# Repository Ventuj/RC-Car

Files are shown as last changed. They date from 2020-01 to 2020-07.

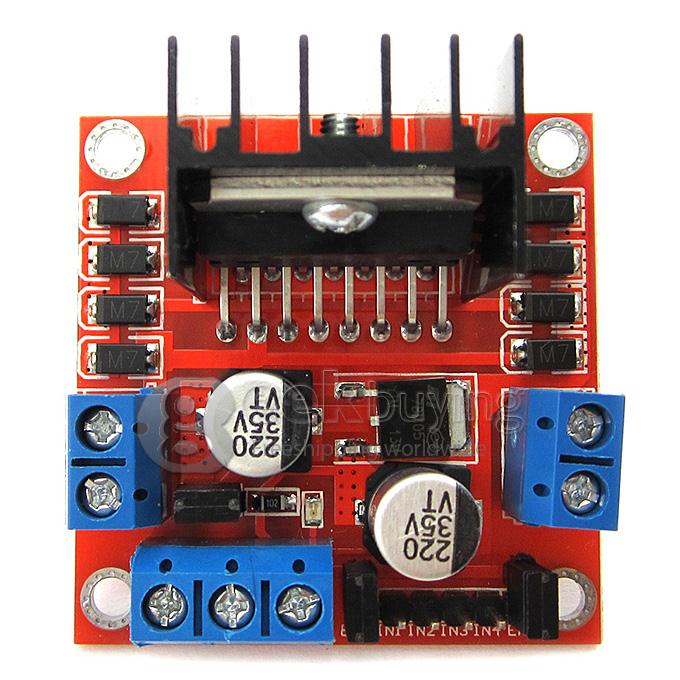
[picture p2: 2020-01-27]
Docs/Img/L298N View.jpg

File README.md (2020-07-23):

# Remote 4x4 Car
Three different version 4x4 RC car with arduino.

# Last Update
Last PCB Shield design is [Gerber_Arduino Mega Shield V2_20200217124525.zip](https://github.com/Daniele-Venturin/RC-Car/blob/master/Docs/Altro/Gerber_Arduino%20Mega%20Shield%20V2_20200217124525.zip)
## V1.0 (IR) Relè & L298N
###### Components
- 1x RGB Led (Optional)
- 2x 1kohm resistors
- 2x 2 Relay
- 4x DC Motors
- 1x HC-SR04 (Ultrasonic Sensor)
- 1x 1838B (iR Receiver)
- 1x Arduino Nano or Arduino UNO
- 1x Buzzer (Optional)
- 2x Battery pack 7-12V

###### PinOut
LED Status
- D3 ➞ Red
- D4 ➞ Green

Signal Reciver
- D5 ➞ IR reciver

Ultrasonic Sensor
- D6 ➞ Echo 
- D7 ➞ Trig

Relay
- D8 ➞ SX1
- D9 ➞ SX2
- D10 ➞ DX1
- D11 ➞ DX2

Sound
- D12 ➞ Buzzer

## V2.0 (Bluetooth)
###### Components
- 1x Custom PCB Shield
- 1x L298N DC Motor driver
- 1x Buzzer (optional)
- 1x RGB Led (optional)
- 1x HC-05 (Bluetooth Module)
- 4x HC-SR04 (Ultrasonic Sensor)
- 4x DC Motors
- 1x Arduino MEGA 2560
- 1x Battery Pack (11,1V 2200 mAh)
- 1x BMS 3S 20C

###### PinOut
Digitali
LED Status
- D8 ➞ Green
- D9 ➞ Red

Sound
- D10 ➞ Buzzer
- D11 ➞ Fari Posteriori
- D12 ➞ Faro Anteriori

Sensori
- D22 ➞ Trig 1
- D23 ➞ Echo 1
- D24 ➞ Trig 2
- D25 ➞ Echo 2
- D26 ➞ Trig 3
- D27 ➞ Echo 3
- D28 ➞ Trig 4
- D29 ➞ Echo 4

Driver Motori
- D2 ➞ Enable 1
- D3 ➞ Input 1
- D4 ➞ Input 2
- D5 ➞ Input 3
- D6 ➞ Input 4
- D7 ➞ Enable 2

Analogici
- A0 ➞ Stop Button 
- A1 ➞ Fotoresistenza

## V3.0 (WI-FI)
###### Components
- 1x Custom Motherboard PCB
- 4x 1kohm resistors (R1-R2-R3-R4)
- 2x 33kohm resistors (R5-R6)
- 1x L298N DC Motor driver
- 1x Buzzer (Optional)
- 1x RGB Led (Optional)
- 1x ESP8266 (WI-FI Module)
- 4x HC-SR04 (Ultrasonic Sensor)
- 4x DC Motors
- 1x Arduino MEGA
- 1x Battery Pack (11,1V 2200 mAh)
- 1x BMS 3S 20C

###### PinOut
Digitali
LED Status
- D8 ➞ Green
- D9 ➞ Red

Sound
- D10 ➞ Buzzer
- D11 ➞ Fari Posteriori
- D12 ➞ Faro Anteriori

Sensori
- D22 ➞ Trig 1
- D23 ➞ Echo 1
- D24 ➞ Trig 2
- D25 ➞ Echo 2
- D26 ➞ Trig 3
- D27 ➞ Echo 3
- D28 ➞ Trig 4
- D29 ➞ Echo 4

Driver Motori
- D2 ➞ Enable 1
- D3 ➞ Input 1
- D4 ➞ Input 2
- D5 ➞ Input 3
- D6 ➞ Input 4
- D7 ➞ Enable 2

Analogici
- A0 ➞ Stop Button 
- A1 ➞ Fotoresistenza

## Docs

###### Wire diagram 

###### Gerber file PCB
Top view of PCB

Top 

Bottom view of PCB

Bottom

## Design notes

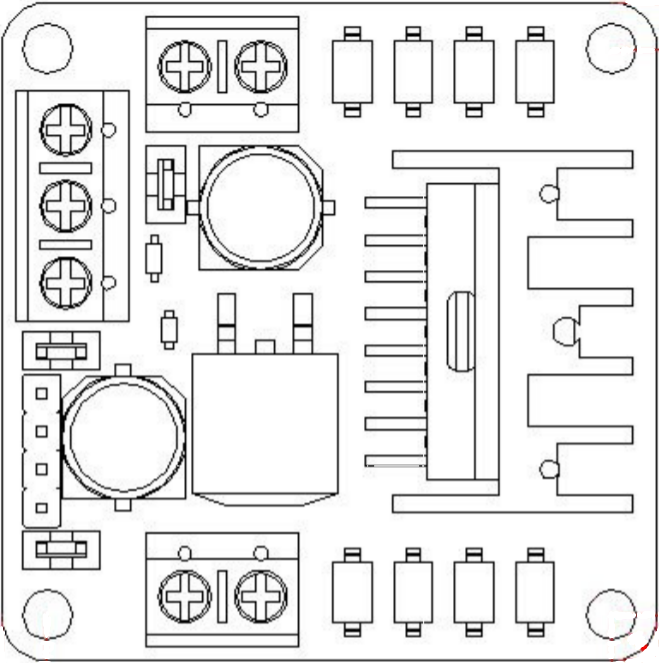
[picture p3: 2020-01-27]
Docs/Img/L298N.png

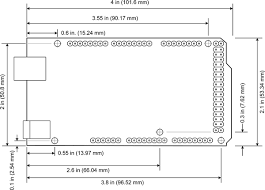
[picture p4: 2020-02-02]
Docs/Img/dimmension.png

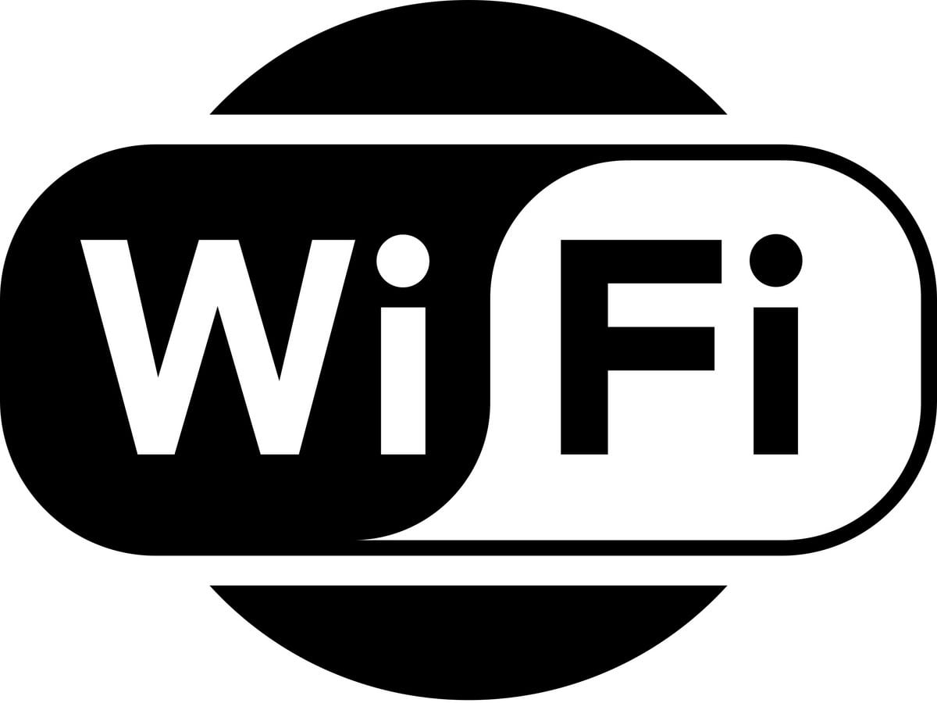
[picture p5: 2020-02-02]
Docs/Img/Benefits-of-wireless-internet-WiFi-over-wired-Connection.jpg

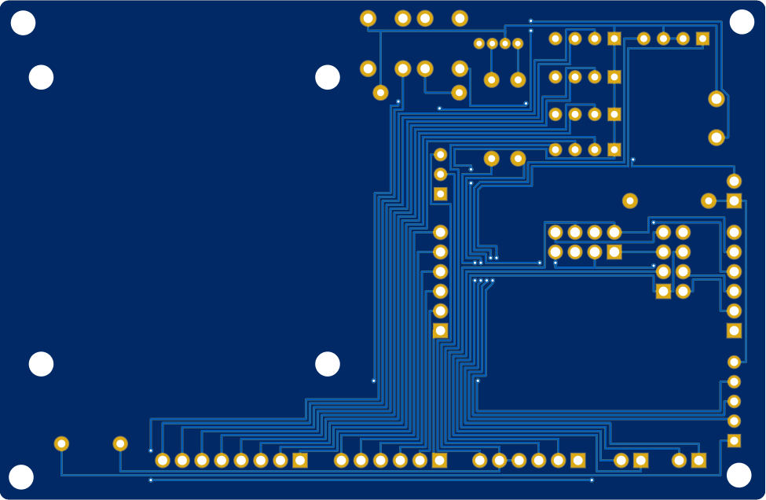
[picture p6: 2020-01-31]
Docs/Img/PCB-Bottom.png

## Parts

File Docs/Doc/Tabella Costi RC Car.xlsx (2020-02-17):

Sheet: sheet1
LCSC Code | Code | Obj | Req Q | Q | Min Q | Price x 1 | Price | Link | Opz 1 | Opz 2 | Extra
C225499 | A2541HWV-2P | Pin 1x2 Femmina | 5 | 20 | 20 | 0.0209 | 0.42 | Link (https://lcsc.com/product-detail/Pin-Header-Female-Header_CJT-Changjiang-Connectors-A2541HWV-2P_C225499.html)
C225500 | A2541HWV-3P | Pin 1x3 Femmina | 10 | 10 | 10 | 0.031 | 0.31 | Link (https://lcsc.com/product-detail/Pin-Header-Female-Header_CJT-Changjiang-Connectors-A2541HWV-3P_C225500.html)
C225501 | A2541HWV-4P | Pin 1x4 Femmina | 25 | 25 | 5 | 0.0636 | 1.59 | Link (https://lcsc.com/product-detail/Pin-Header-Female-Header_CJT-Changjiang-Connectors-A2541HWV-4P_C225501.html)
C225503 | A2541HWV-6P | Pin 1x6 Femmina | 20 | 20 | 5 | 0.0915 | 1.83 | Link (https://lcsc.com/product-detail/Pin-Header-Female-Header_CJT-Changjiang-Connectors-A2541HWV-6P_C225503.html)
C225505 | A2541HWV-8P | Pin 1x8 Femmina | 20 | 20 | 5 | 0.0795 | 0.4 | Link
C239344 | A2541HWV-2x4P | Pin 2x4 Femmina | 5 | 5 | 1 | 0.127 | 0.64 | Link (https://lcsc.com/product-detail/Pin-Header-Female-Header_CJT-Changjiang-Connectors-A2541HWV-2x4P_C239344.html)
C239345 | A2541HWV-2x5P | Pin 2x5 Femmina | 10 | 10 | 1 | 0.1133 | 1.13 | Link (https://lcsc.com/product-detail/Pin-Header-Female-Header_CJT-Changjiang-Connectors-A2541HWV-2x5P_C239345.html)
C60375 | C60375 | Pin 2x14 Femmina | 5 | 5 | 5 | 0.074 | 0.37 | Link (https://lcsc.com/product-detail/Pin-Header-Female-Header_BOOMELE-Boom-Precision-Elec-C60375_C60375.html)
C225481 | A2541WV-6P | Pin 1x6 Maschio | 5 | 5 | 5 | 0.0209 | 0.42 | Link (https://lcsc.com/product-detail/Pin-Header-Female-Header_CJT-Changjiang-Connectors-A2541WV-6P_C225481.html)
C225483 | A2541WV-8P | Pin 1x8 Maschio | 25 | 25 | 1 | 0.0778 | 1.95 | Link (https://lcsc.com/product-detail/Pin-Header-Female-Header_CJT-Changjiang-Connectors-A2541WV-8P_C225483.html)
C225519 | A2541WV-2x4P | Pin 2x4 Maschio | 5 | 5 | 1 | 0.1066 | 0.53 | Link (https://lcsc.com/product-detail/Pin-Header-Female-Header_CJT-Changjiang-Connectors-A2541WV-2x4P_C225519.html)
C168945 | C168945 | Pin 2x18 Maschio | 5 | 5 | 1 | 0.0993 | 0.5 | Link (https://lcsc.com/product-detail/Pin-Header-Female-Header_Ckmtw-Shenzhen-Cankemeng-C168945_C168945.html)
C98733 | XT60 | XT 60A connector | 5 | 5 | 5 | 0.3852 | 1.93 | Link (https://lcsc.com/product-detail/Lithium-Ion-Model-Connectors_Changzhou-Amass-Elec-XT60_C98733.html)
C72334 | WJ500V-5.08-3P | PCB Socket 3P | 5 | 5 | 1 | 0.1109 | 0.55 | Link (https://lcsc.com/product-detail/Screw-terminal_Ningbo-Kangnex-Elec-WJ500V-5-08-3P_C72334.html)
C273365 | 200MSP1T1B1M2QEH | PCB Switch | 5 | 5 | 1 | 2.1317 | 10.66 | Link (https://lcsc.com/product-detail/Toggle-Switches_E-Switch-200MSP1T1B1M2QEH_C273365.html)
/ | / | PCB | 5 | 5 | 5 | 0.366 | 1.83 | /
/ | HC-05 | Bluetooth Module | 5 | 5 | 5 | 4.8 | 25.99 | Link (https://www.amazon.it/AZDelivery-ricetrasmettitore-wireless-Bluetooth-Comunicazione/dp/B07BHRG9KB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)
/ | ESP8266 | Wi-FI Module | 5 | 5 | 5 | 3 | 14.99 | Link (https://www.amazon.it/AZDelivery-esp8266-Raspberry-Microcontroller-Gratuito/dp/B074RLG5TC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)
/ | L298N | DC Driver | 5 | 5 | 5 | 2.8 | 13.99 | Link (https://www.amazon.it/Electrely-Bridge-Stepper-Controller-Arduino/dp/B07GFGS6BN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)
/ | 18650 Li-ion Battery | Rechargeble battery | 15 | 15 | 1 | 13.22 | 66.1 | Link (https://www.akkuteile.de/samsung-inr18650-25r-2500mah-3-7v_100657_1258) |  |  | Spedizione inclusa
/ | / | Battery Holder | 5 | 5 | 5 | 1.998 | 9.99 | Link (https://www.amazon.it/gp/product/B075V25QJ9/ref=ox_sc_act_title_5?smid=A3TCAMEHRX2HS1&psc=1)
/ | BSM - 3S 20A | Battery Balance block | 5 | 5 | 5 | 2.2 | 11 | Link (https://www.amazon.it/gp/product/B07688W1XG/ref=crt_ewc_img_dp_4?ie=UTF8&psc=1&smid=A80IWAZC4BCUO)
/ | Battery Pack | Rhino 2200mAh 3S 25C Lipo Pack XT60 | 5 | 5 | 1 | 10.054 | 50.27 | Link (https://hobbyking.com/en_us/rhino-2200mah-3s-25c-lipo-pack-w-xt60.html) |  |  | Spedizione inclusa
 |  |  |  | Opz 1 (Hobby King) |  | Opz 2 (Akkuteile)
 |  | Componenti (LCSC + JLCPCB) € | 25.06 | 24.51 |  | 23.13
 |  | Spedizione € | 22.32 | 22.32 |  | 22.32
 |  | Componenti + spedizione € | 47.38 | 46.83 |  | 45.45
 |  | Amazon € | 75.96 | 64.96 |  | 75.96
 |  | Hobbyking € | 50.27 | 50.27 |  | 0
 |  | Akkuteile € | 66.1 | 0 |  | 66.1
 |  | Totale € | / | 162.06 |  | 187.51
 |  | Costo x Auto |  | 32.412 |  | 37.502

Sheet: Foglio1
/ | HC-SR04 | Ultrasonic Sensor | 20 | 18 | 3 | 1.996666667 | 35.94 | Link (https://www.amazon.it/dp/B00R2U8HK6/ref=twister_B01LZ7NHTF?_encoding=UTF8&psc=1)
/ | 18650 Li-ion Battery | Rechargeble battery | 15 | 15 | 1 | 3.48 | 52.2 | Link (https://www.akkuteile.de/samsung-inr18650-25r-2500mah-3-7v_100657_1258) | 11,68€ di spedizione

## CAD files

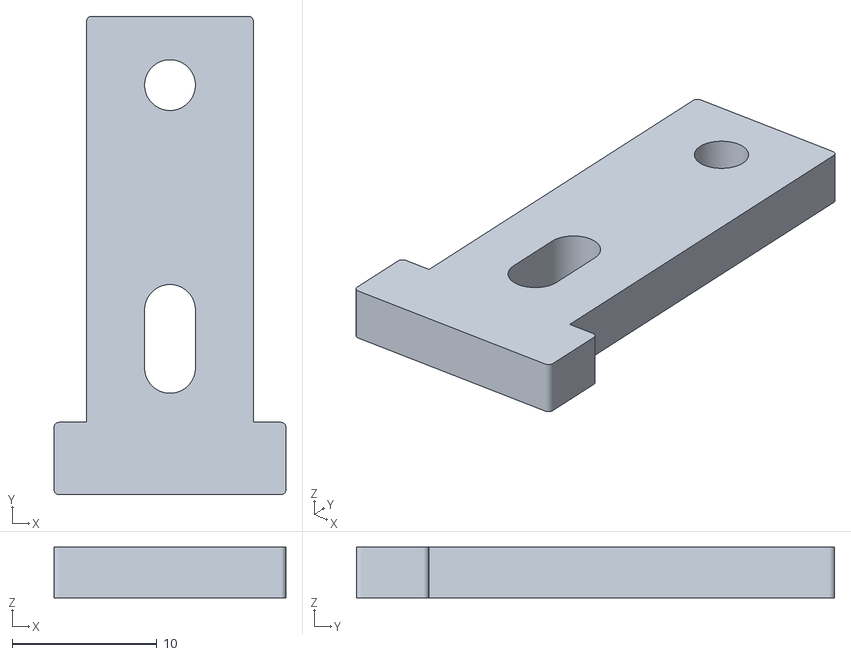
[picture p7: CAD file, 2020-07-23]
3D Component/Riparazione.stl
16.0 x 33.0 x 3.50

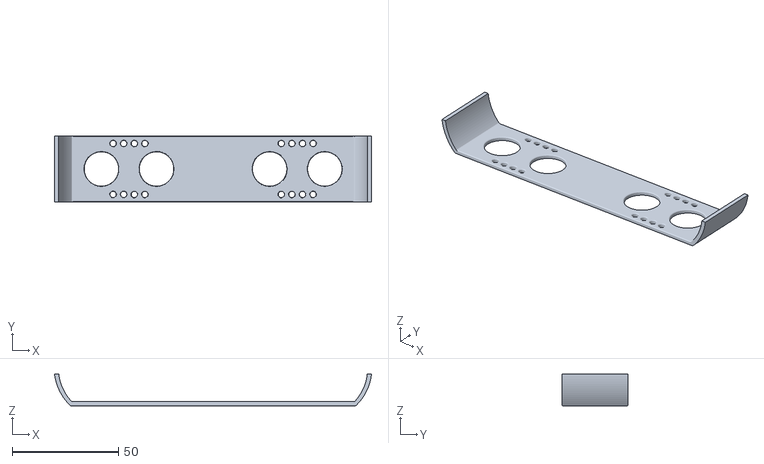
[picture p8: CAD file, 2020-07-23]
3D Component/M7.stl
149.5 x 31.0 x 15.0

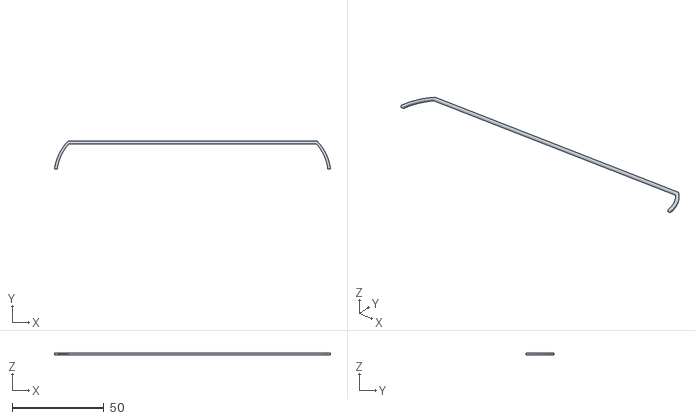
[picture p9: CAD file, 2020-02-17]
3D Component/M2.stl
150.5 x 15.0 x 1

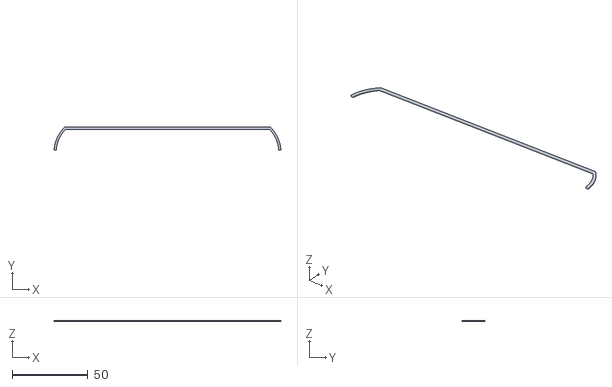
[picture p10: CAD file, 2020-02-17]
3D Component/M1.stl
150.0 x 15.0 x 0.8

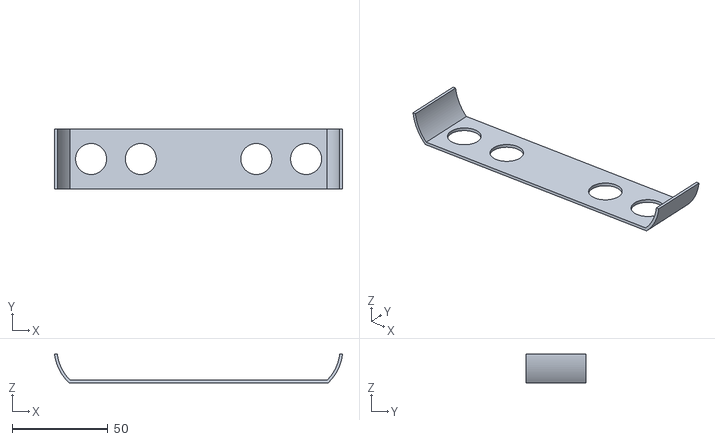
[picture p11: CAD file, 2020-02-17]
3D Component/M4.stl
150.5 x 31.5 x 15.0

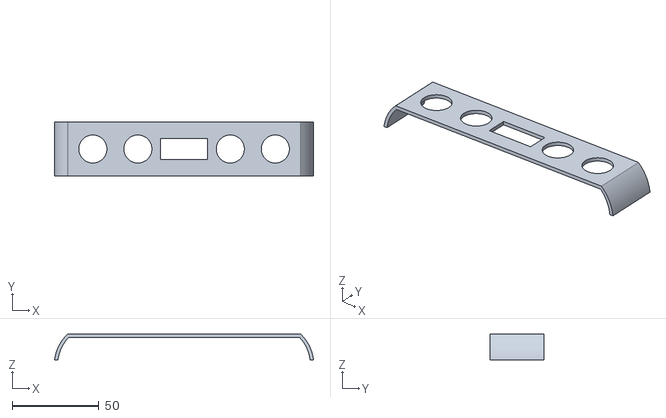
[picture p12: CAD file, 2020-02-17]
3D Component/M6.stl
149.5 x 31.0 x 15.0

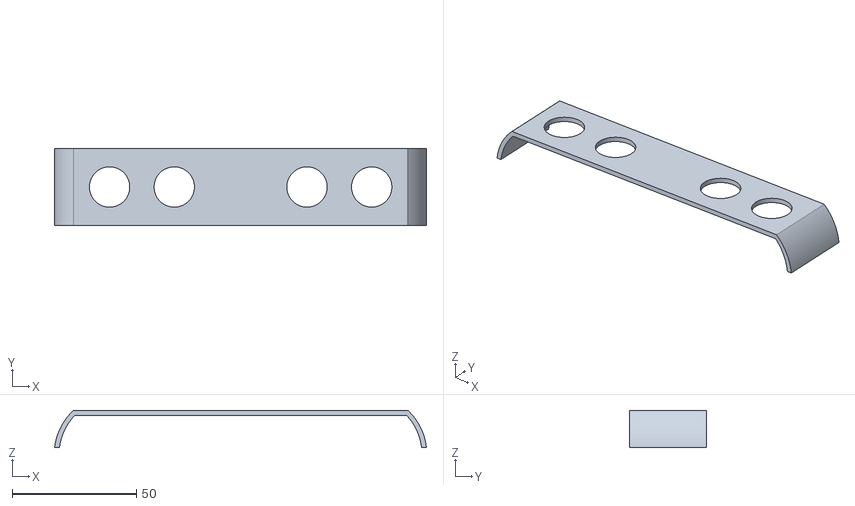
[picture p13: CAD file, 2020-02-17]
3D Component/M5.stl
149.5 x 31.0 x 15.0

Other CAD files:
3D Component/M3.stl

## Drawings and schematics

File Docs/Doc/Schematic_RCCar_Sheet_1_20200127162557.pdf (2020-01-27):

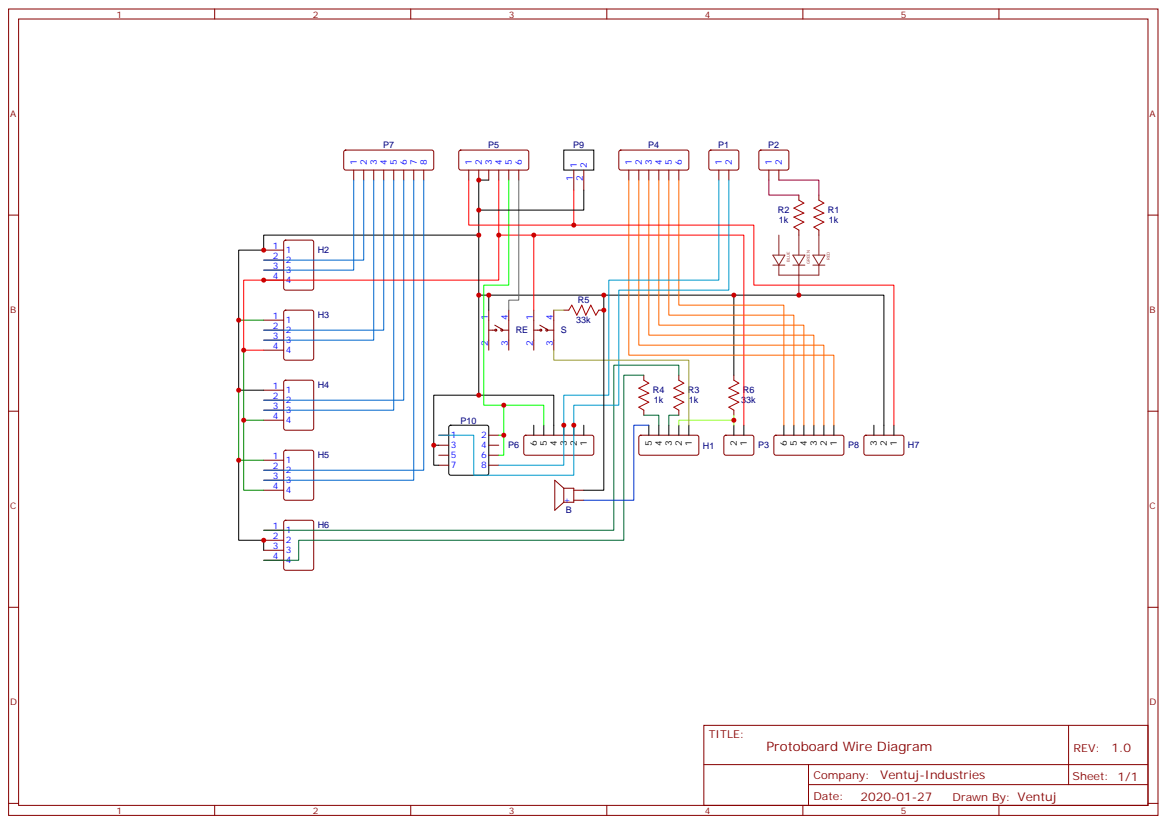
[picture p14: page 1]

Company: Ventuj-Industries RED

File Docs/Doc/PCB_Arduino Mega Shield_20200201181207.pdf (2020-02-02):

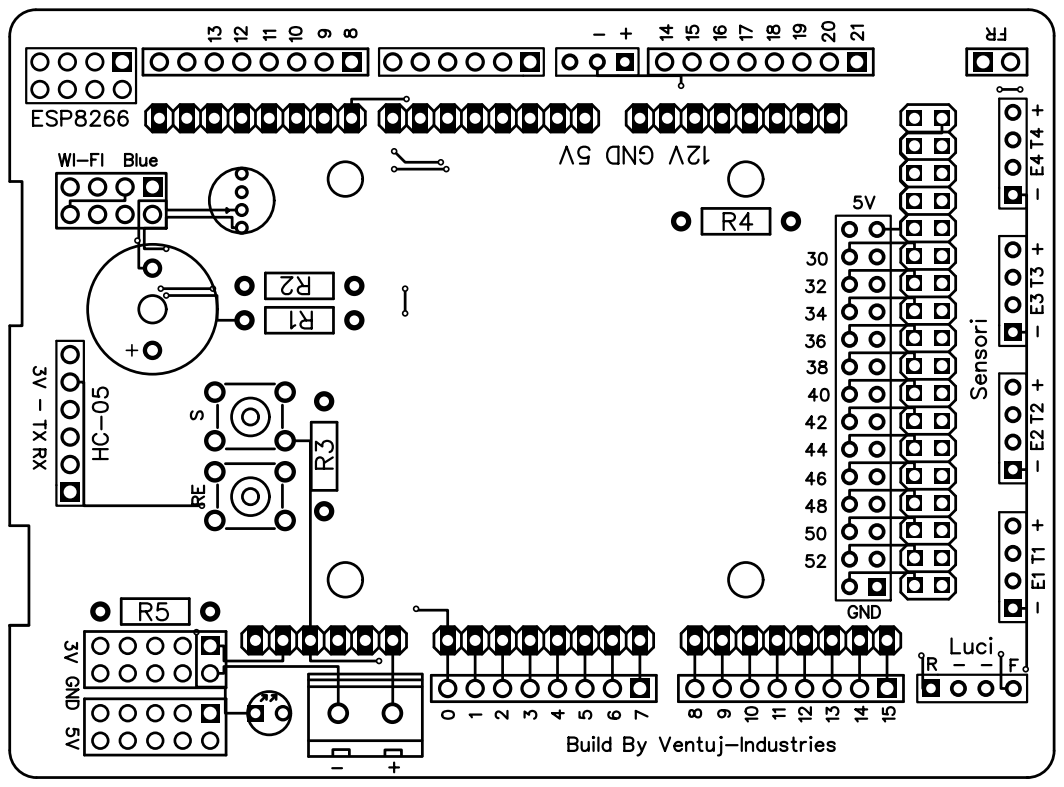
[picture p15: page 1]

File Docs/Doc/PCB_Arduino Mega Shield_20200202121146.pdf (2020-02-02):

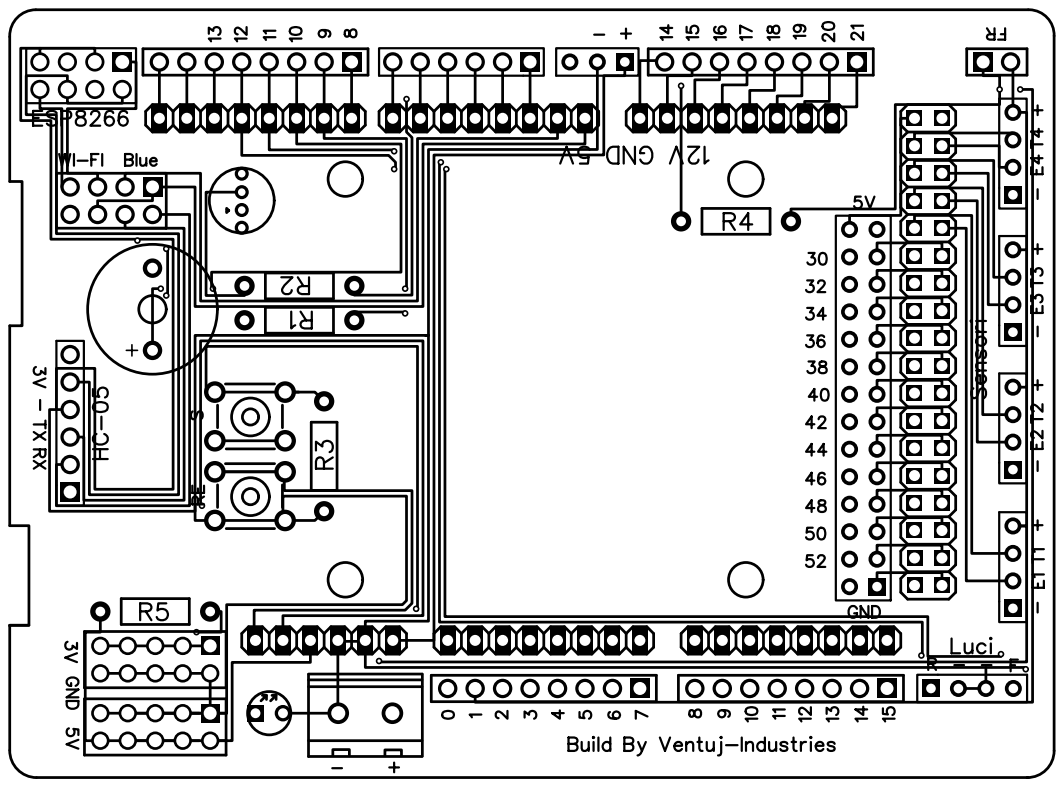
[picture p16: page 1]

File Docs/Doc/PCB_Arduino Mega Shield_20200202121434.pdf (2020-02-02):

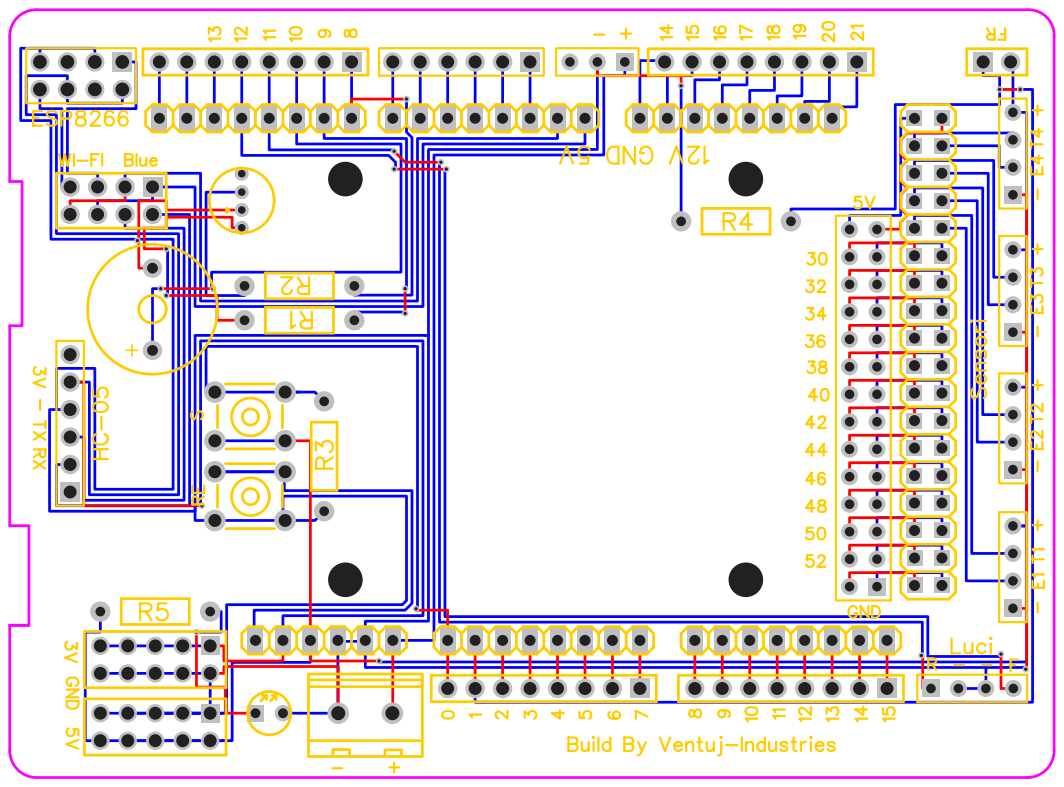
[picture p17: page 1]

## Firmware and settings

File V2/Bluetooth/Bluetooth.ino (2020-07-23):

int led = 8;
//driver
int E1 = 2;
int M1 = 3;
int M2 = 4;
int M3 = 5;
int M4 = 6;
int E2 = 7;
//sensori
int T1 = 22;
int C1 = 23;
int T2 = 24;
int C2 = 25;


//speed
int clockPin = 19; //pin 11 19
int latchPin = 18; //pin 12 18
int dataPin = 17; //pin 14 17


//fari 
int clockPin1 = 14; //pin 11 16 
int latchPin1 = 15; //pin 12 15
int dataPin1 = 16; //pin 14 14 

int pot = A1;

int perc = 80;
//int Speed = (perc * 255) / 100;

int Speed;
int distanza;

int green = 8;
int red = 9;

byte test[] = {
  B00000000,
  B10000000,
  B11000000,
  B11100000,
  B11110000,
  B11111000,
  B11111100,
  B11111110,
  B11111111
};

byte fari[] = {
  B10000001,
  B11000011,
  B11100111,
};

byte fari1[] = {
  B11100111,
  B11000011,
  B10000001,
};
void setup(){
  Serial.begin(9600);
  //EEBlue.begin(9600);
  pinMode(E1, OUTPUT);
  pinMode(E2, OUTPUT);
  pinMode(M1, OUTPUT);
  pinMode(M2, OUTPUT);
  pinMode(M3, OUTPUT);
  pinMode(M4, OUTPUT);
  
  pinMode(T1, OUTPUT);
  pinMode(C1, INPUT);
  pinMode(T2, OUTPUT);
  pinMode(C1, INPUT);
  pinMode(led, OUTPUT);
  //analogWrite(led, 20);
    
  pinMode(dataPin, OUTPUT);
  pinMode(latchPin, OUTPUT);
  pinMode(clockPin, OUTPUT);
  
  pinMode(dataPin1, OUTPUT);
  pinMode(latchPin1, OUTPUT);
  pinMode(clockPin1, OUTPUT);
  pinMode(pot, INPUT);
  pinMode(green, OUTPUT);
  pinMode(red, OUTPUT);
  
  digitalWrite(red, HIGH);
  
  while (!Serial) {
    ; // wait for serial port to connect. Needed for native USB port only
  }
  Serial.println("Connssione con RC Car avvenuta!");
  Serial.println();

  turnoff();
}

bool check = false;
bool inserimento = false;

bool av = false;
bool ind = false;
bool manovra = false;

bool faro = false;

int dist[4] = {0,0,0,0};

//movimenti
void ferma(){
  int val = 0;
  if(faro){
    val = 255;
  }
  //posteriori
  digitalWrite(latchPin1, LOW);
  shiftOut(dataPin1, clockPin1, MSBFIRST, val);
  shiftOut(dataPin1, clockPin1, MSBFIRST, 255);
  digitalWrite(latchPin1, HIGH); 
  //analogWrite(led, 250);
  for(int i = Speed; i > 20; i--){
    analogWrite(E1, i);
    analogWrite(E2, i);
    delay(5);
  }
  //analogWrite(led, 20);
  digitalWrite(M1, LOW);
  digitalWrite(M2, LOW);
  digitalWrite(M3, LOW);
  digitalWrite(M4, LOW);
  //posteriori
  digitalWrite(latchPin1, LOW);
  shiftOut(dataPin1, clockPin1, MSBFIRST, val);
  shiftOut(dataPin1, clockPin1, MSBFIRST, 0);
  digitalWrite(latchPin1, HIGH); 
}

void avanti(){
  analogWrite(E1, Speed);
  analogWrite(E2, Speed);
  digitalWrite(M1, LOW);
  digitalWrite(M2, HIGH);
  digitalWrite(M3, LOW);
  digitalWrite(M4, HIGH);
}

void indietro(){
  analogWrite(E1, Speed);
  analogWrite(E2, Speed);
  digitalWrite(M1, HIGH);
  digitalWrite(M2, LOW);
  digitalWrite(M3, HIGH);
  digitalWrite(M4, LOW);
}

void dx(){
  analogWrite(E1, Speed);
  analogWrite(E2, Speed);
  digitalWrite(M1, HIGH);
  digitalWrite(M2, LOW);
  digitalWrite(M3, LOW);
  digitalWrite(M4, HIGH);
}

void sx(){
  analogWrite(E1, Speed);
  analogWrite(E2, Speed);
  digitalWrite(M1, LOW);
  digitalWrite(M2, HIGH);
  digitalWrite(M3, HIGH);
  digitalWrite(M4, LOW); 
}

int distance(int t, int e){
  long duration = 0;
  int distance = 0;
  digitalWrite(t, LOW);
  delayMicroseconds(2);
  digitalWrite(t, HIGH);
  delayMicroseconds(10);
  digitalWrite(t, LOW);
  duration = pulseIn(e, HIGH);
  distance = duration*0.034/2;
  //Serial.println(distance);
  return distance;
}
void velocita(){
  int vpot = analogRead(pot);
  int var = map(vpot, 0,1023, 0, 9);
  Speed = map(vpot, 0,1023, 30, 256);
  distanza = map(vpot, 0, 1023, 4, 15);
  digitalWrite(latchPin, LOW);           
  shiftOut(dataPin, clockPin, MSBFIRST, test[var]);
  digitalWrite(latchPin, HIGH);   
  if(av){
    avanti();       
  }else{
    if(ind){
      indietro();
    }
  }
}

void loop() {
  velocita();
  if(check){
    if(dist[0] < distanza){
      av = false;
      indietro();
      Serial.println("Ho trovato un ostacolo!");
      delay(100);
      ferma();
    }
    if(dist[1] < distanza){
      av = false;
      indietro();
      Serial.println("Ho trovato un ostacolo!");
      delay(100);
      ferma();
    }
  }
  if (Serial.available()){
    char ch = Serial.read();
    if(ch == '0'){
      if(check){
        av = ind = check = false;
        Serial.println("Macchina stoppata");
        digitalWrite(red, HIGH);
        digitalWrite(green, LOW);
        ferma();
      }else{
        check = true;
        digitalWrite(red, LOW);
        digitalWrite(green, HIGH);
        Serial.println("Macchina avviata");
        Serial.println("Powered By Ventuj-Industries");
      }
    }
    if(ch == 'f'){
      if(faro){
        faro = false;
        for(int i = 0; i < sizeof(fari1); i++){
          digitalWrite(latchPin1, LOW);        
          shiftOut(dataPin1, clockPin1, MSBFIRST, fari1[i]);
          shiftOut(dataPin1, clockPin1, MSBFIRST, 0);
          digitalWrite(latchPin1, HIGH); 
          delay(70);
        }       
        digitalWrite(latchPin1, LOW);      
        shiftOut(dataPin1, clockPin1, MSBFIRST, 0);  
        shiftOut(dataPin1, clockPin1, MSBFIRST, 0);
        digitalWrite(latchPin1, HIGH); 
      }else{
        faro = true;
        for(int i = 0; i < sizeof(fari); i++){
          digitalWrite(latchPin1, LOW);
          shiftOut(dataPin1, clockPin1, MSBFIRST, fari[i]);
          shiftOut(dataPin1, clockPin1, MSBFIRST, 0);
          digitalWrite(latchPin1, HIGH); 
          delay(70);
        }       
        digitalWrite(latchPin1, LOW);      
        shiftOut(dataPin1, clockPin1, MSBFIRST, 255);
        shiftOut(dataPin1, clockPin1, MSBFIRST, 0);
        digitalWrite(latchPin1, HIGH); 
      }
    }
    if(check){
      if(ch == '1'){
        if(av){
          av = false;
          Serial.println("Avanti - OFF");
          ferma();
        }else{
          Serial.println("Avanti - ON");
          ind = false;
          av = true;
          avanti();
        }
      }
      if(ch == '2'){
        if(ind){
          Serial.println("Indietro - OFF");
          ind = false;
          ferma();
        }else{
          Serial.println("Indietro - ON");
          av = false;
          ind = true;
          indietro();
        }
      }
      if(ch == '3'){
        manovra = true;
        Serial.println("Destra");
        if(av || ind){
          if(av){
            dx();
            delay(200);
            avanti();
          }else{
            dx();
            delay(200);
            indietro(); 
          }
        }else{
          dx();
          delay(200);
          ferma();
        }
        manovra = false;
      }
      if(ch == '4'){
        manovra = true;
        Serial.println("Sinistra");
        if(av || ind){
          if(av){
            sx();
            delay(200);
            avanti();
          }else{
            sx();
            delay(200);
            indietro(); 
          }
        }else{
          sx();
          delay(200);
          ferma();
        }
        manovra = false;
      }
    }
  }
  dist[0] = distance(T1, C1);
  dist[1] = distance(T2, C2);
}

void turnoff(){
  digitalWrite(latchPin1, LOW);      
  shiftOut(dataPin1, clockPin1, MSBFIRST, 0);
  shiftOut(dataPin1, clockPin1, MSBFIRST, 0);
  digitalWrite(latchPin1, HIGH); 
}

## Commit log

2020-02-02 Upload Data
    [Tabella Costi RC Car.xlsx]
2020-02-17 Upload Docs + 3D Model
    [M1.stl, M2.stl, M3.stl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]
2020-02-17 Update New PCB Image
2020-02-17 Upload new gerber PCB File
2020-02-22 Add PWM regulation Sys
2020-07-23 Modifiche stutturali / adattamento PCB
2020-07-23 Update 3D Model
    [M7.stl]
2020-07-23 Upload Backup componet
    [Riparazione.stl]
2020-07-23 Update pcb model
2020-07-23 Upload New PCB File
